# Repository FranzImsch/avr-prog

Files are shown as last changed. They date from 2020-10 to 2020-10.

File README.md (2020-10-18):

# AVR-Prog
Basic Programmer for AVR-Chips. It's based off the [Sparkfun Tiny AVR Programmer](https://github.com/sparkfun/Tiny-AVR-Programmer).

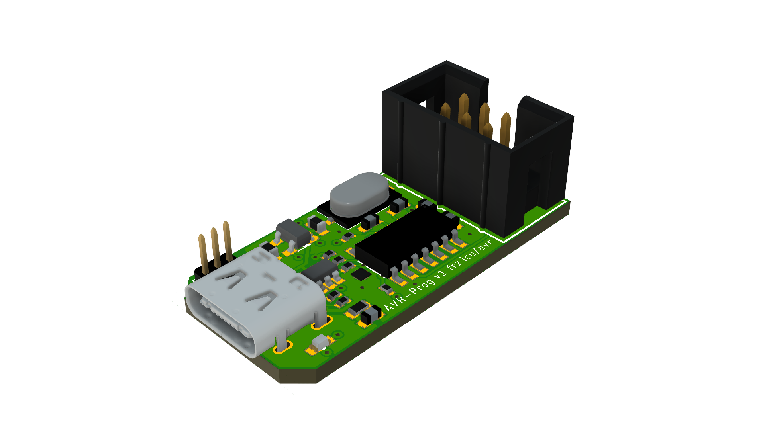
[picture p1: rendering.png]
Rendering


Features are:
- USB-C connector,
- 5V or 3V3 logic level,
- Tag-Connect connector.

## Partlist

|Name |Component |Package |
|---|---|---|
|C1, C3 |100nF Cap |0603 |
|C2 |10µF Cap |0603 |
|C4, C5 |2.2µF Cap |0603 |
|C6, C9 |18pF Cap |0603 |
|IC1 |ATTINY84A-SSU |SOIC127P600X175-14N |
|J1 |JUMPER 3x 1.27mm | |
|J3 |Box Header 6P | |
|LED |LED |0603 |
|R1 |1K Resistor |0402 |
|R2, R9 |68Ω Resistor |0402 |
|R3 |1K5 Resistor |0402 |
|R4 |10KΩ Resistor |0603 |
|R6, R7 |5K1 Resistor |0402 |
|R8 |10K Resistor |0402 |
|U$1 |USB-C Connector |TYPE-C16PIN |
|U$2 |TLV75533PDBVR |SOT23-5 |
|U$3 |SRV05-4-P-T7 |SOT23-6 |
|X1 |KMD160001210 |M-49USSMD |

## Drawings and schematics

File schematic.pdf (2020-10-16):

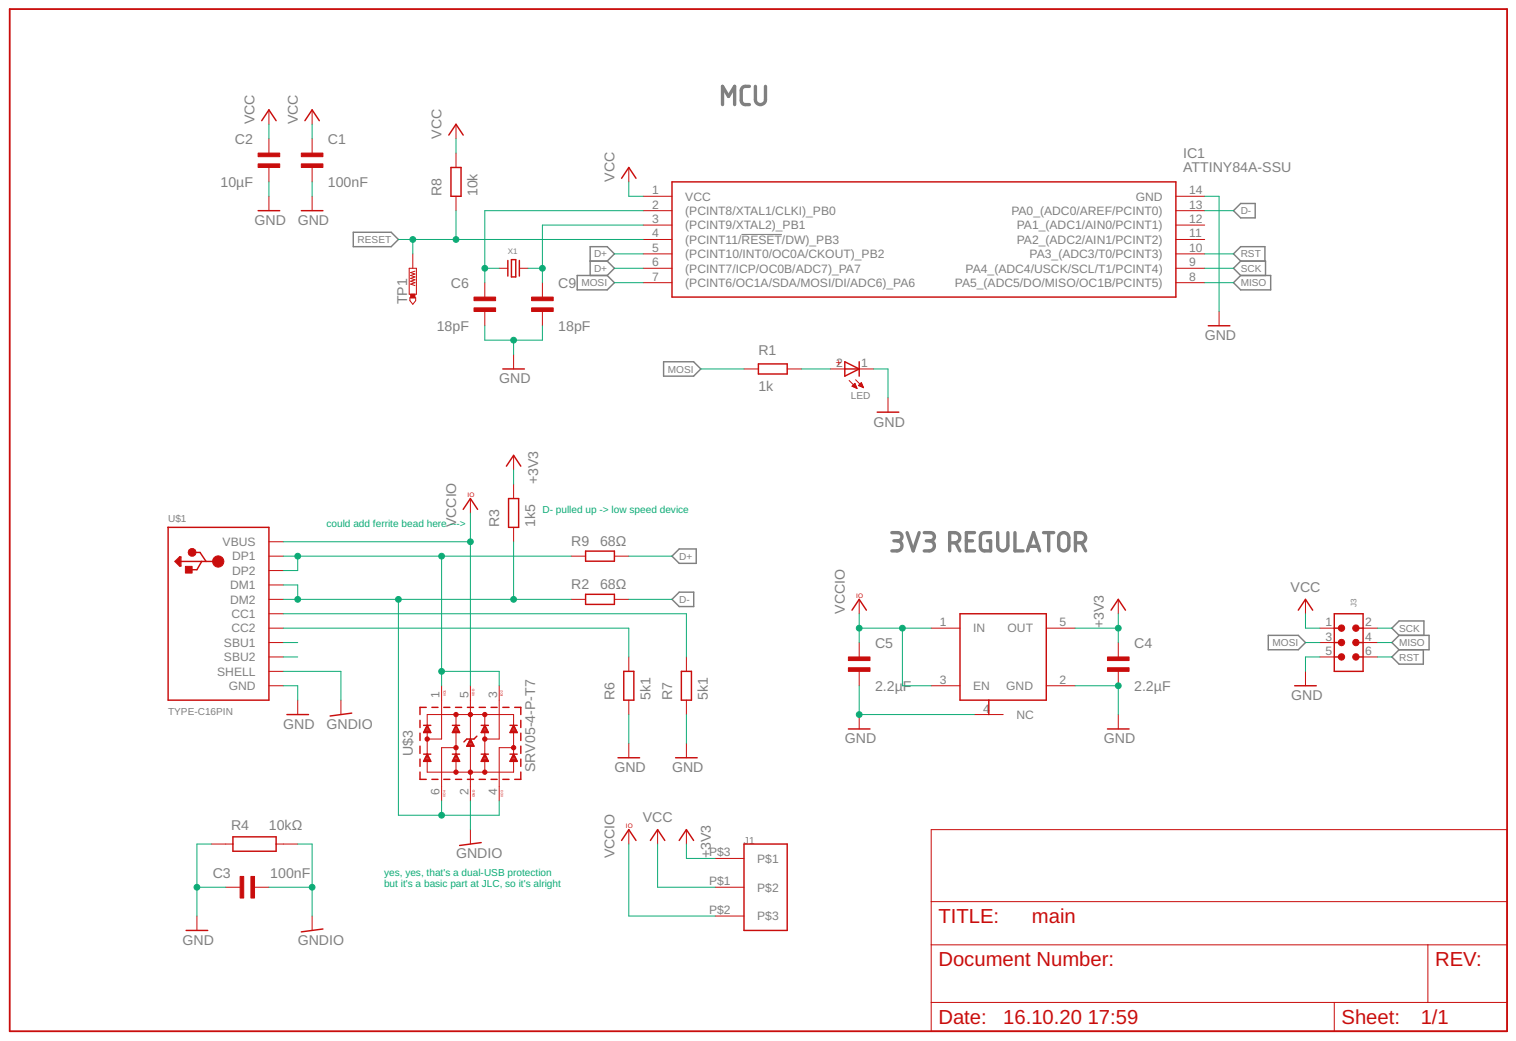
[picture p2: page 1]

yes, yes, that's a dual-USB protection
but it's a basic part at JLC, so it's alright

Document Number: | REV:

Date: 16.10.20 17:59 | Sheet: 1/1

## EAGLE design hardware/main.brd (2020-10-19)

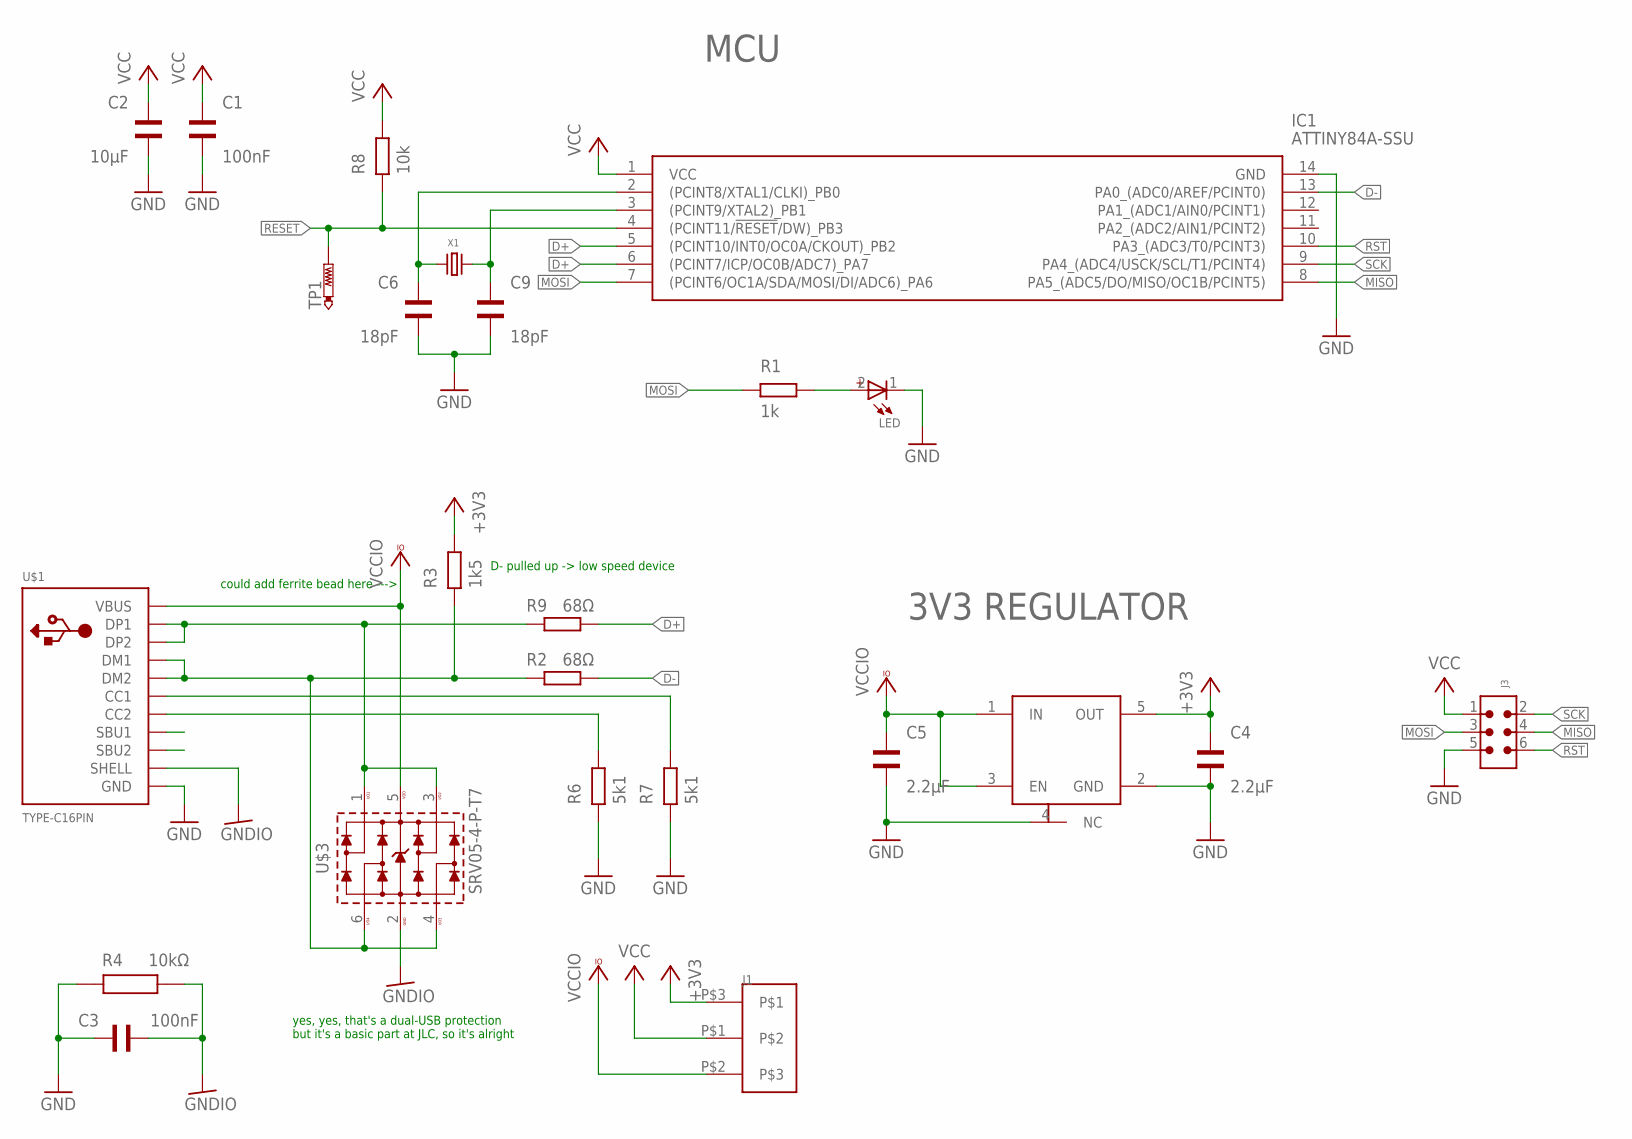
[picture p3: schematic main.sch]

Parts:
C1, C3: 100nF; WCAP-CSGP_0603_REFLOW
C2: 10µF; WCAP-CSGP_0603_REFLOW
C4, C5: 2.2µF; WCAP-CSGP_0603_REFLOW
C6, C9: 18pF; WCAP-CSGP_0603_REFLOW
IC1: ATTINY84A-SSU; SOIC127P600X175-14N
J1: JUMPER1.27; 1.27_JUMPER
J3: 6120XX21621_61200621621; 61200621621
LED: WL-SMCW_0603_150060GS75000; WL-SMCW_0603
R1: 1k; WRIS-KSKE_0402
R2, R9: 68Ω; WRIS-KSKE_0402
R3: 1k5; WRIS-KSKE_0402
R4: 10kΩ; WRIS-PSMB_0603_1.6X0.8X0.35X0.6(LXWXHXPW)
R6, R7: 5k1; WRIS-KSKE_0402
R8: 10k; WRIS-KSKE_0402
TP1: PTR1B1,27; B1,27
U$1: TYPE-C16PIN
U$2: TLV75533PDBVRSOT-23-5; DBV_R-PDSO-G5
U$3: SRV05-4-P-T7; SOT23-6
X1: KMD160001210; M-49USSMD

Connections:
+3V3: C4.2, J1.P$3, R3.2, U$2.5 (OUT)
D+: IC1.5 ((PCINT10/INT0/OC0A/CKOUT)_PB2), IC1.6 ((PCINT7/ICP/OC0B/ADC7)_PA7), R9.2
D+_RAW: R9.1, U$1.A6 (DP1), U$1.B6 (DP2), U$3.1 (IO1), U$3.3 (IO2)
D-: IC1.13 (PA0_(ADC0/AREF/PCINT0)), R2.2
D-_RAW: R2.1, R3.1, U$1.A7 (DM1), U$1.B7 (DM2), U$3.4 (IO3), U$3.6 (IO4)
GND: C1.1, C2.1, C3.2, C4.1, C5.1, C6.1, C9.1, IC1.14 (GND), J3.5, LED.1 (-), R4.1, R6.1, R7.1, U$1.A1B12 (GND), U$1.B1A12 (GND), U$2.2 (GND), U$2.4 (NC)
GNDIO: C3.1, R4.2, U$1.SHELL1 (SHELL), U$1.SHELL2 (SHELL), U$1.SHELL3 (SHELL), U$1.SHELL4 (SHELL), U$3.2 (GND)
MISO: IC1.8 (PA5_(ADC5/DO/MISO/OC1B/PCINT5)), J3.4
MOSI: IC1.7 ((PCINT6/OC1A/SDA/MOSI/DI/ADC6)_PA6), J3.3, R1.1
unnamed: LED.2 (+), R1.2
unnamed: R7.2, U$1.A5 (CC1)
unnamed: R6.2, U$1.B5 (CC2)
unnamed: C6.2, IC1.2 ((PCINT8/XTAL1/CLKI)_PB0), X1.P$1 (1)
unnamed: C9.2, IC1.3 ((PCINT9/XTAL2)_PB1), X1.P$2 (2)
RESET: IC1.4 ((PCINT11/!RESET!/DW)_PB3), R8.1, TP1.TP
RST: IC1.10 (PA3_(ADC3/T0/PCINT3)), J3.6
SCK: IC1.9 (PA4_(ADC4/USCK/SCL/T1/PCINT4)), J3.2
VCC: C1.2, C2.2, IC1.1 (VCC), J1.P$1, J3.1, R8.2
VCCIO: C5.2, J1.P$2, U$1.A4B9 (VBUS), U$1.B4A9 (VBUS), U$2.1 (IN), U$2.3 (EN), U$3.5 (VDD)

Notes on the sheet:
MCU
3V3 REGULATOR
yes, yes, that's a dual-USB protection but it's a basic part at JLC, so it's alright
could add ferrite bead here --->
D- pulled up -> low speed device

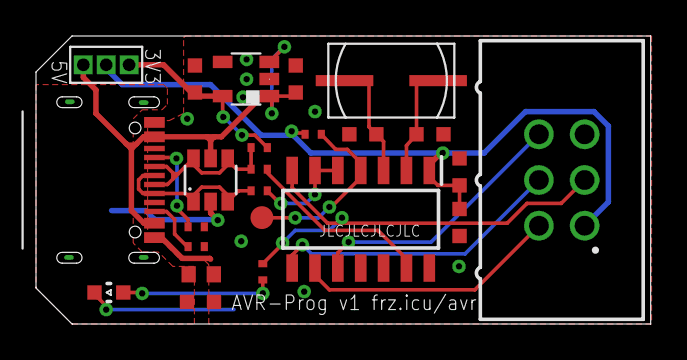
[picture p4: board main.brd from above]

Board: 2 copper layers, 34.1 x 16.0 mm, 24 parts (0 on the bottom side), 19 nets.

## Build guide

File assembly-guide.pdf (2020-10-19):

AVR-prog Assembly Guide frz.icu/avr

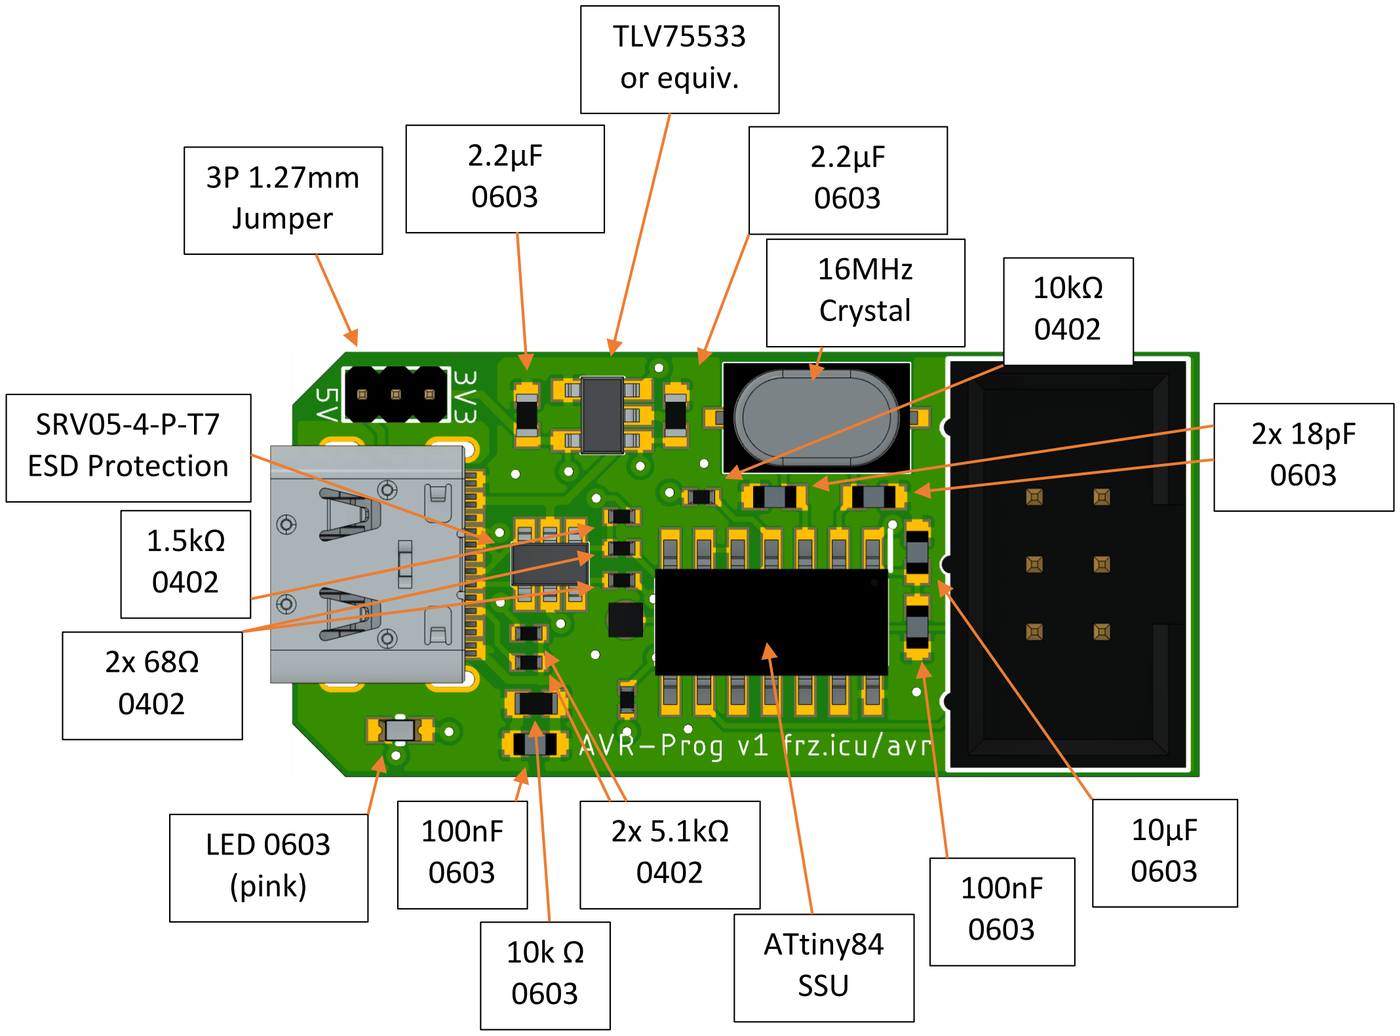
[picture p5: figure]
3P 1.27mm Jumper; TLV75533 or equiv.; 16MHz Crystal; LED 0603 (pink); SRV05-4-P-T7 ESD Protection; ATtiny84 SSU

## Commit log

2020-10-13 initialising repo
    [main.sch]
2020-10-19 added assembly guide
    [main.brd]

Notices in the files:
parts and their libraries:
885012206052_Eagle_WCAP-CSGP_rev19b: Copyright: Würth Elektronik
